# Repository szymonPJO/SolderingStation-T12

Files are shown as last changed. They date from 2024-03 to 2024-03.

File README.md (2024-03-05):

# Soldering station T12

<table>
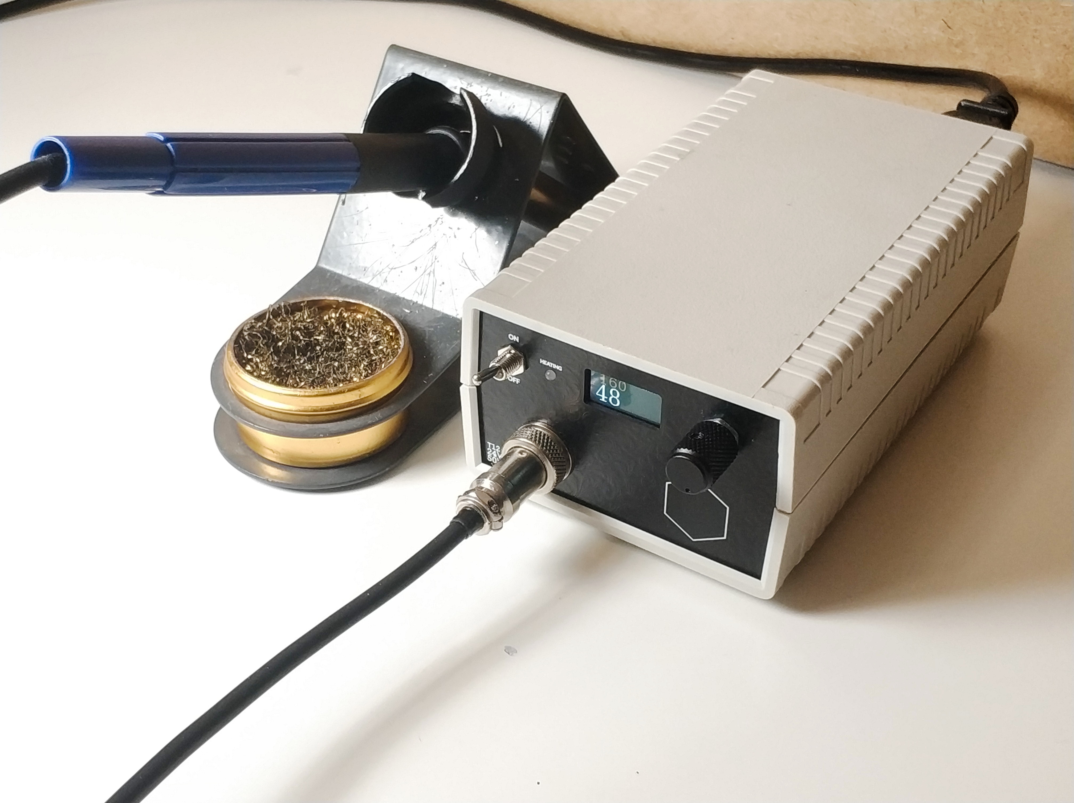
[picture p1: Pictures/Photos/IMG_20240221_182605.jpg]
station view 1
    <td></td>
</table>

## Specification:

- **Ramp-up Time**: 5 seconds to achieve 200°C
- **Measurement Accuracy**: up to ±5%
- **Power**: 75W
- **Instability (Consistency) of Set Temperature**: ±0.2°C
- **Temperature Range**: 0 – 500°C (from room temperature)
- **Number of ADC Samples**: 250
- **Measurement Time** / **Percentage of Measurement Duration (Heating Off)**: 1.4ms / 1.4% (or 0.9ms / 0.9% for temperatures >150°C)
- **PWM Frequency** / **Measurement Frequency**: 50Hz / 10Hz
- **Other**: (futures below)

<!-- # About my motivation

elektroda.
*Translated site from polish! -->

### Features:

- T12 Tips Compatibile
- IPS Display
  - Current and Set Temperature in `°C`
  - Power Output Bar Indicator
  - Settings (PID and GUI)
- Rotary Encoder
- Touch Button (stop/start heating)
- Heating LED
- Switch 230VAC
- Front Panel - PCB made
- Connector GX16 (easy tips replacement)

#### Software Features:

- Efficient Temperature Setting - PID Controller
- Memory - Eeprom
- Autosleep (todo)

## Schematics

<table>
    <tr><img src="Pictures/Mainboard-Schematic.png" alt="Mainboard-Schematic""></tr>
    <tr>
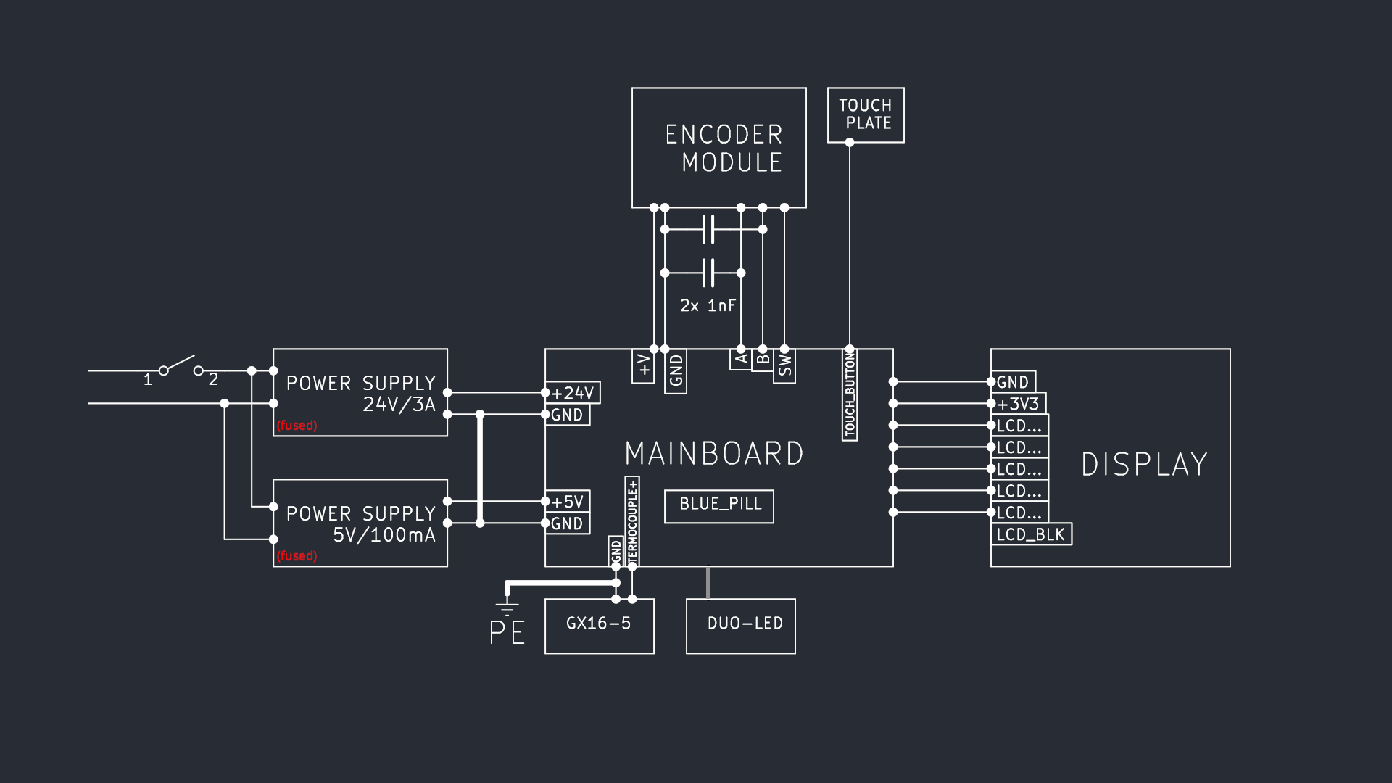
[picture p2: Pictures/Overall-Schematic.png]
Overall-Schematic
        <td></td>
    </tr>
</table>

## Software requirments

[stlink](https://github.com/stlink-org/stlink?tab=readme-ov-file), kicad (optional)

## Flashing

It's required debuger for flash STM32. STLINK-V2 clone is fine.

```bash
st-flash --reset write soldering-*.bin 0x08000000
```

If you have error then it's probably stm32 clone. It's ok. Blue-Pill boards have clons often. Check `st-info --chipid`. For clones "chipid" is 0 instead 0x0410 or similar. Try to flash with my config file.

```bash
st-flash -c doc/BP_clone.cfg --reset write soldering-*.bin 0x08000000
```

## Assembly Guide

1. First take a look at overall BOM below. Next check [PCB BOM online][preview-bom-v1] or as file in `PCB/{version}/bom/ibom.html`. (I suggest to dowload the repo this point)

   | Part                  | Description                                             | Photo                                                                    |
   | --------------------- | ------------------------------------------------------- | ------------------------------------------------------------------------ |
   | PCB components        | All important components from [PCB BOM][preview-bom-v1] |                                                                          |
   | Housing               | Gainta G762                                             |                                                                          |
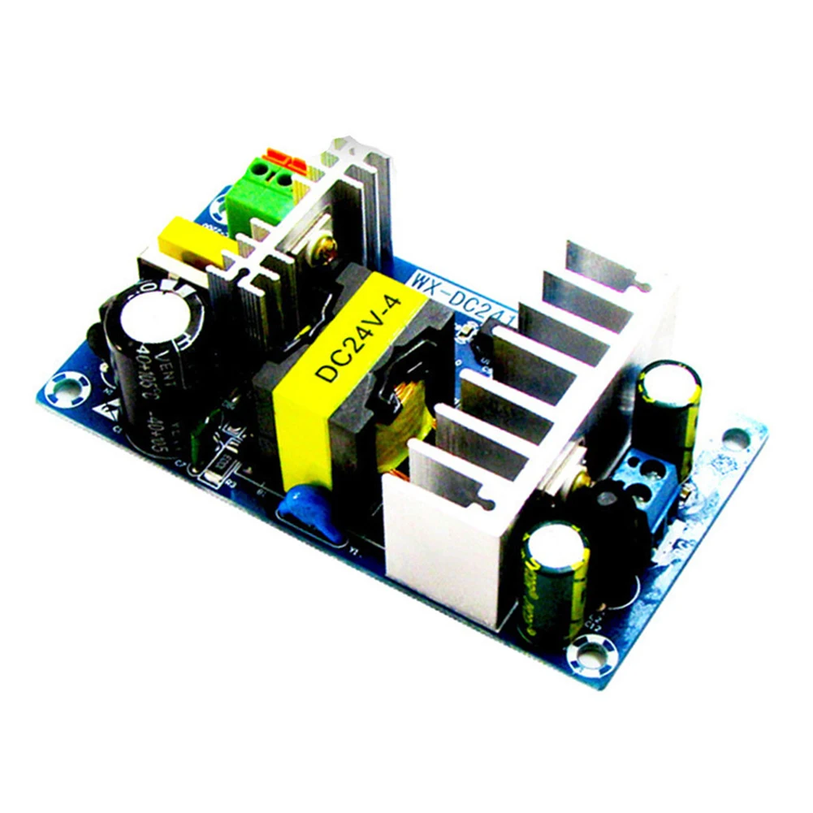
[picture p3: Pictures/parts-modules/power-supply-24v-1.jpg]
   | Power Supply 24V      | 24V/3A or more current (e.g. 24V/4A)                    |     |
   | Power Supply 5V       | 5V/100mA or more current                                |                                                                          |
   | MCU                   | Blue Pill board                                         |                                                                          |
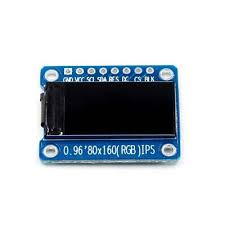
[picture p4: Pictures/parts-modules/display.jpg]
oled
   | Display               | ST7735 SPI 160x80 0.96" module                          |     |
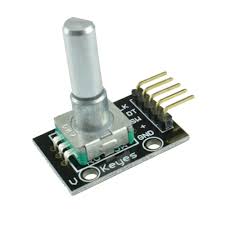
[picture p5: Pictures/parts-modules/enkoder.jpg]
encoder
   | Encoder               | Rotary Encoder module                                   |  |
   | Soldering Iron Socket | GX16-5 Socket                                           |                                                                          |
   | Front Panel           | PCB front panel (project in repo folder)                |                                                                          |
   | Knob                  | Knob for encoder                                        |                                                                          |
   | AC Switch             | SPDT                                                    |                                                                          |
   | Other components      | LED or duoLED 3mm, 2x 1nF THT                           |                                                                          |

   Make sure u have all what you need to DIY. Good to check all parts works berore u start assembly

2. If u making PCB by own, remember to:
   <!-- - U can use _Ready-to-print.pdf_ for e.g. iron-on method -->

   - Protect copper by e.g. Rosin
   - Solder wires from "F.cu" layer (may be before drilling, except two connections)
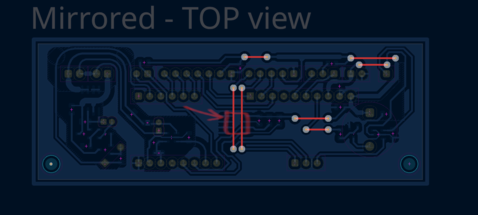
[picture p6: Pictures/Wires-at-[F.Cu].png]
Tekst zastępczy
     

   If u order PCB, remember u can also order PCB-front-board together

3. Soldering SMD (**after drilling**) - BOM [online][preview-bom-v1] or `PCB/*/bom/` can help
4. Soldering THT
5. Mount 24V power supply to device housing and **make separation** between PCB (Plan this housing from mountings things inside)

6. Make power wires from overall schematic for: _Switch, Power suplies, AC connector_ (**Isolate 230V wires and connections**)
7. Make wires and solder from overall schematic (for: _Display, Encoder, etc_) and add 2x 1nF to Encoder module if there is no capacitors
8. **Isolate** and Mount (glue) 5V power supply
9. Connect all together, burn binary and **check that's working**
10. Glue OLED while device works (it would be easier to nice match) to (if u have) PCB-front-board.
11. Let's put everything together now

### Additional assembly tips

- **Be careful** with **AC Power**

- required tools:

  - some working soldering iron (it's funny, but not ironically)
  - some glue (e.g. hotglue or b7000)
  - drilling machine, drills: ~3mm, 0,7mm, 0,9mm (look at kicad brd)
  - tweezer
  - (optional) crimping tool for Dupont Connectors

- good to use:

  - 2.54mm angle pin header + Dupont female Connectors

- Front Panel

  U have to order PCB or drill by CNC. Alternativly try to print 'cut edges' on paper and cut housing plastic plate by knife / drill. The G762 housing have bit soft plastic (maybe ABS) - front/back plates.

## Gallery

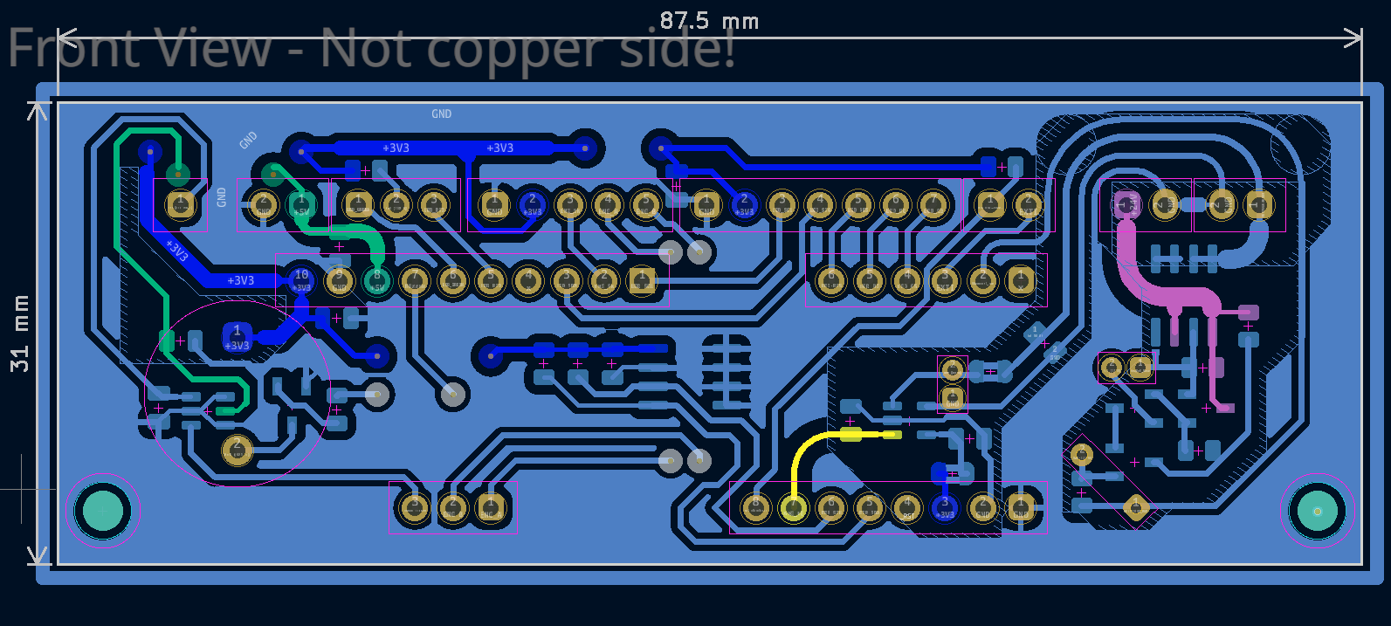
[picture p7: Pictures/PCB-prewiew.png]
PCB preview

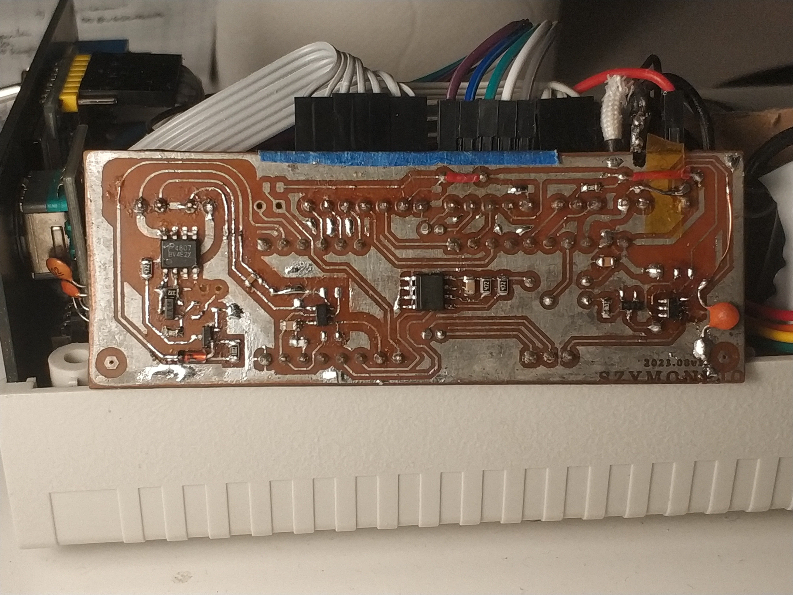
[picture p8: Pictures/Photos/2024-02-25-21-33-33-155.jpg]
PCB after soldering


Check the `Pictures/` folder! :)

---

#### Imagined Concept:

What I decide to leave at concept phase:

- 907 tips compatibility
- tips recognizing
- measurement of thermocouple cold junction thermistor
- optional li-ion power

### Contributing

Feel free to open Pull Request or some Issue

---



[preview-bom-v1]: https://html-preview.github.io/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

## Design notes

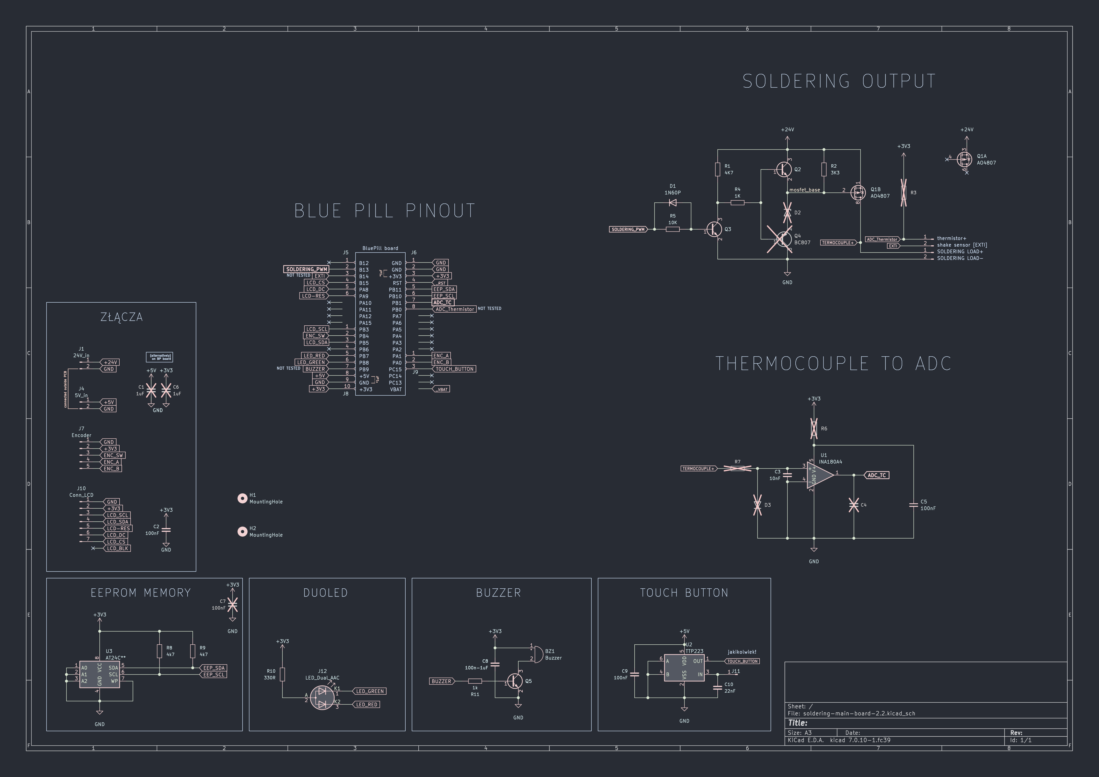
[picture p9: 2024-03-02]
Pictures/Mainboard-Schematic.png

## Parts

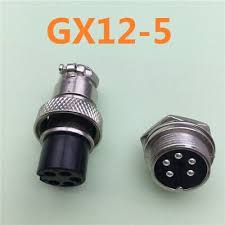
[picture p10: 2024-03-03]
Pictures/parts-modules/GX12-5.jpg

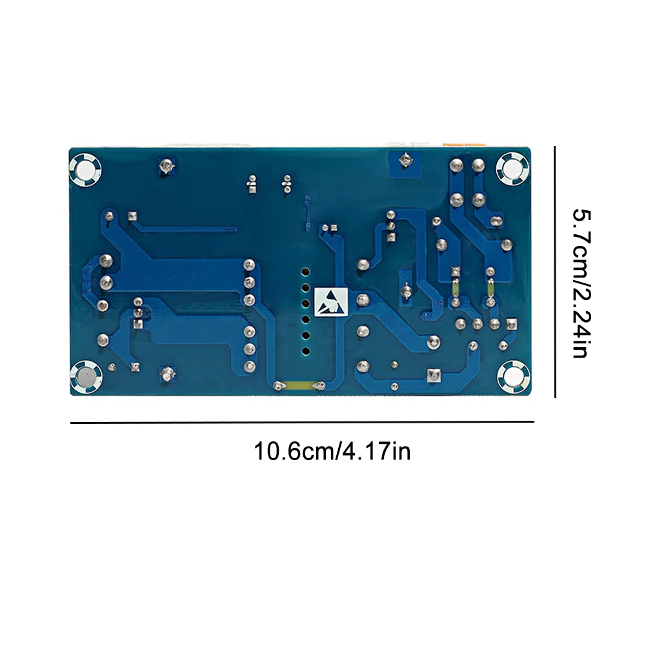
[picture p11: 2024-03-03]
Pictures/parts-modules/power-supply-24v-2.jpg

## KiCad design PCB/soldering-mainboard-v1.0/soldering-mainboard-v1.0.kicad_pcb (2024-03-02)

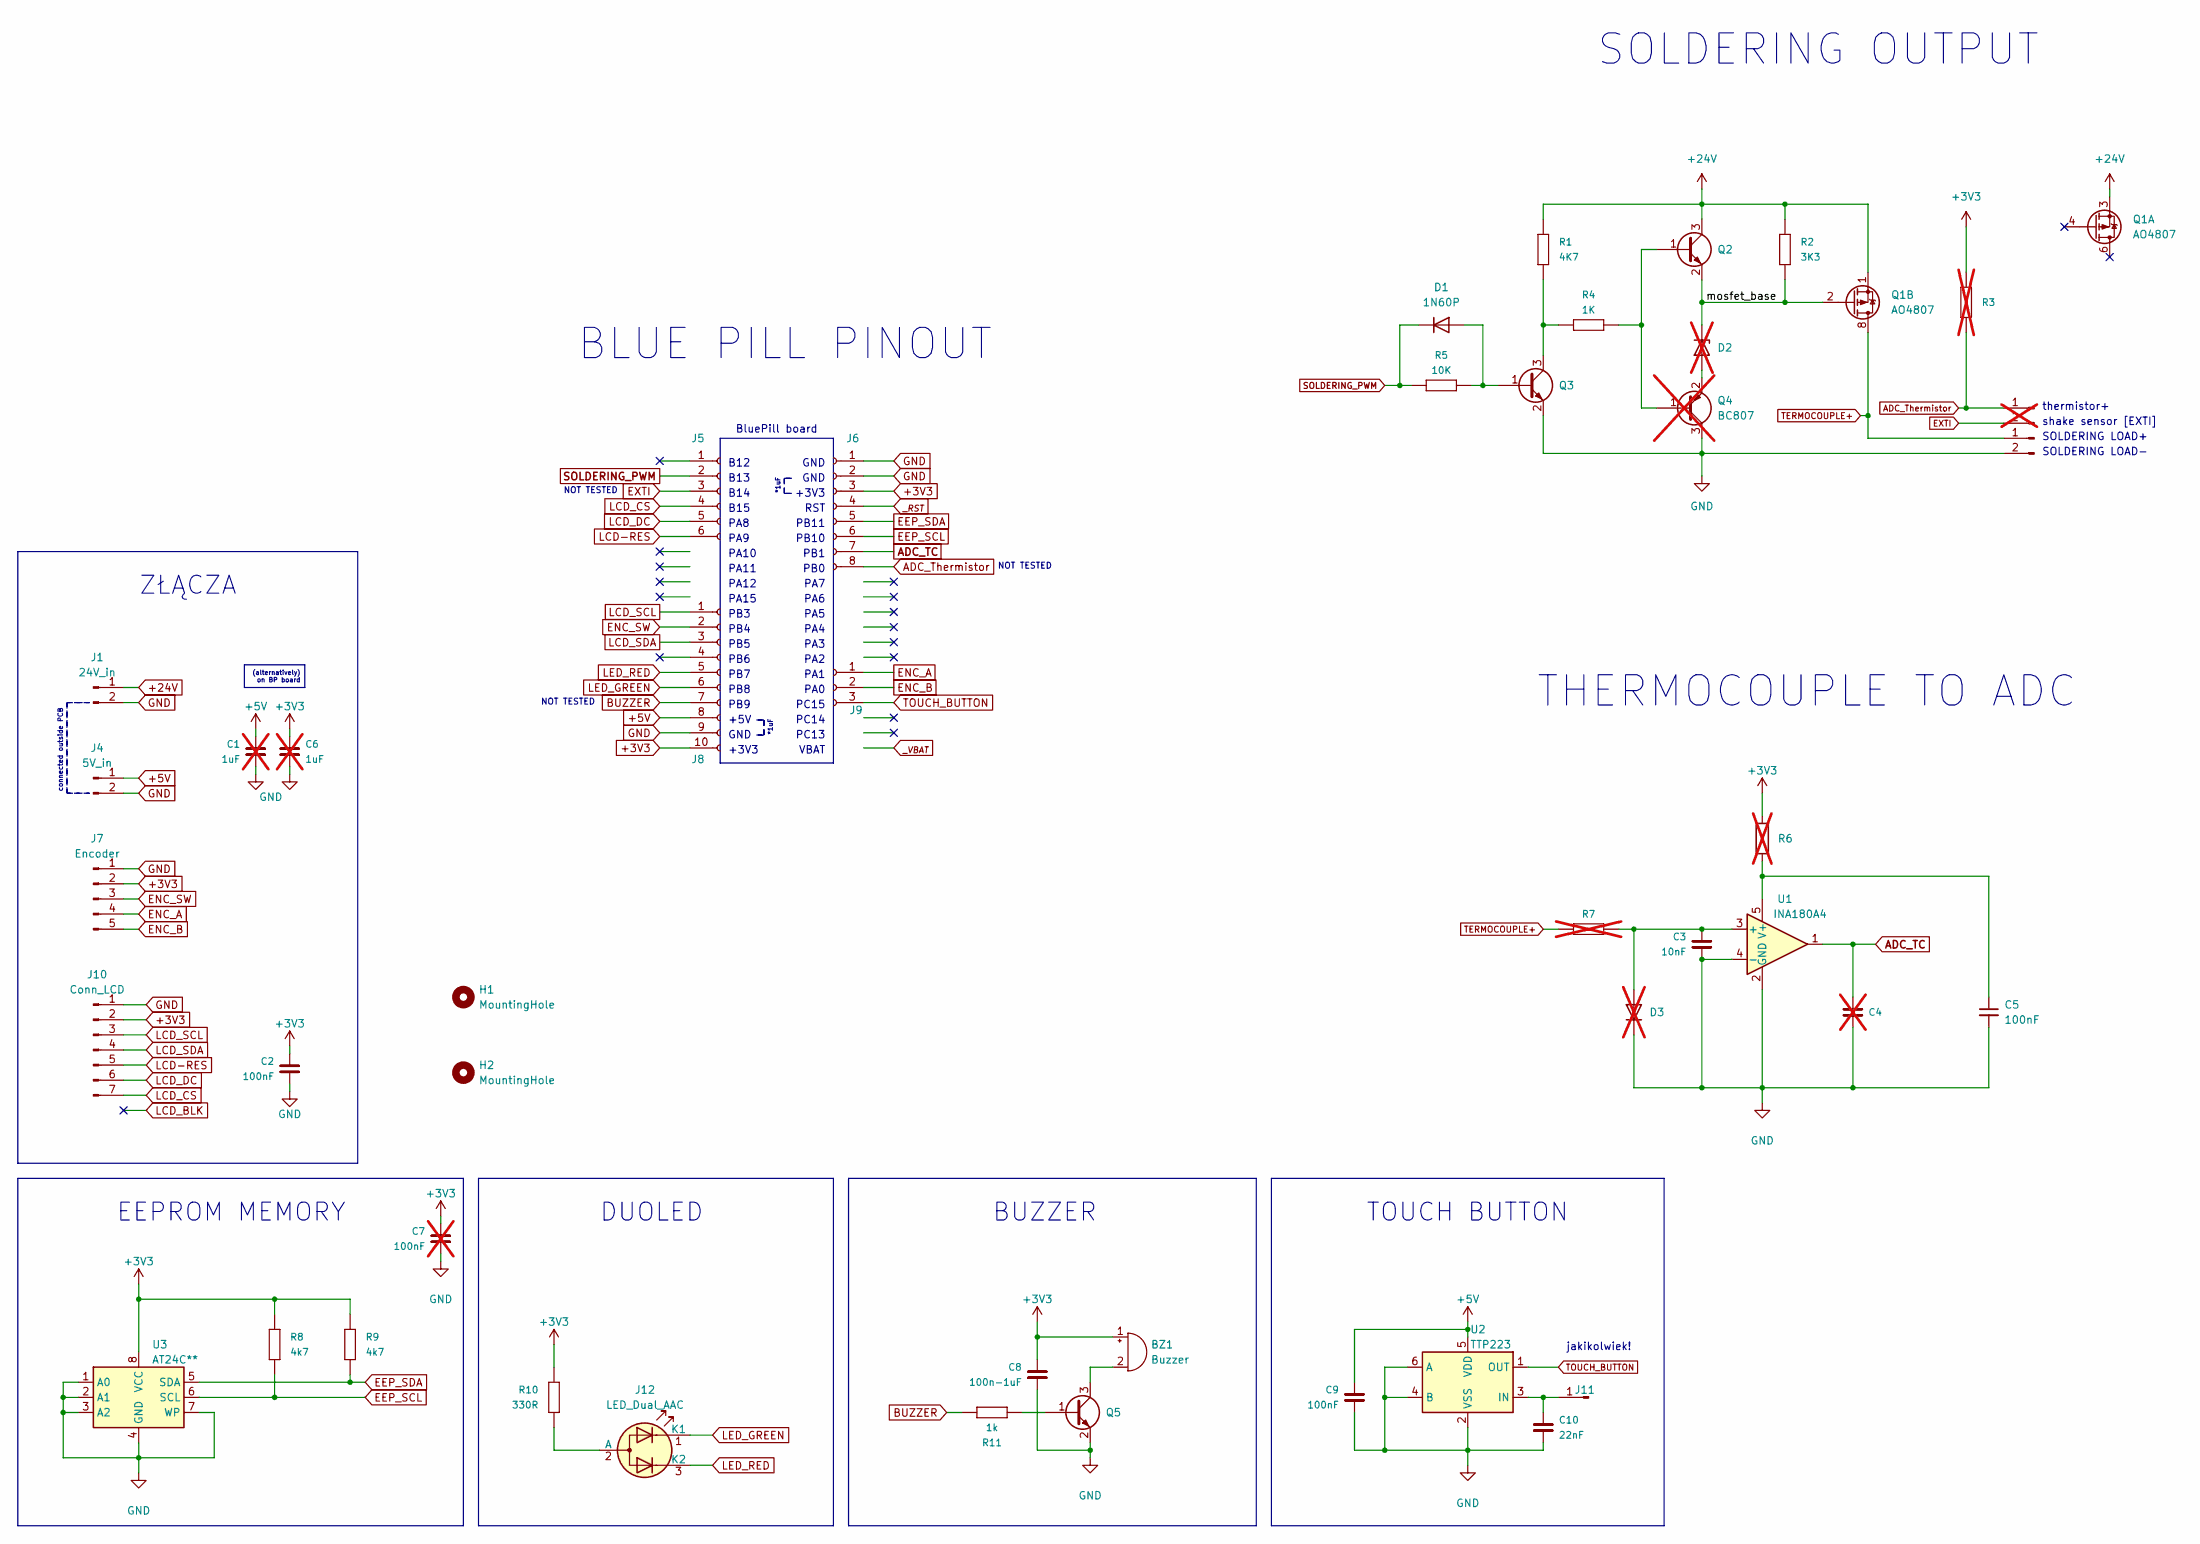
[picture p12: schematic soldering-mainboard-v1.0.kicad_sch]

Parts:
BZ1: Buzzer; Buzzer_12x9.5RM7.6
C1, C6: 1uF; C_0805_2012Metric; not fitted
C2, C5, C9: 100nF; C_0805_2012Metric
C3: 10nF; C_0805_2012Metric
C4: C_0805_2012Metric; not fitted
C7: 100nF; C_0805_2012Metric; not fitted
C8: 100n-1uF; C_0805_2012Metric
C10: 22nF; C_0805_2012Metric
D1: 1N60P; D_DO-34_SOD68_P5.08mm_Vertical_AnodeUp
D2, D3: D_Axial_P1.90mm_Vertical; not fitted
H1, H2: MountingHole; MountingHole_2.7mm_M2.5_ISO14580
J1: 24V_in; PinHeader_1x02_P2.54mm_Vertical
J2: PinHeader_1x02_P2.54mm_Vertical; not fitted
J3: Soldering Iron; PinHeader_1x02_P2.54mm_Vertical
J4: 5V_in; PinHeader_1x02_P2.54mm_Vertical
J5: Conn_01x06_Socket; PinSocket_1x06_P2.54mm_Vertical
J6: Conn_01x08_Socket; PinSocket_1x08_P2.54mm_Vertical
J7: Encoder; PinHeader_1x05_P2.54mm_Vertical
J8: Conn_01x10_Socket; PinSocket_1x10_P2.54mm_Vertical
J9: Conn_01x03_Socket; PinSocket_1x03_P2.54mm_Vertical
J10: Conn_LCD; PinHeader_1x07_P2.54mm_Vertical
J11: Conn_01x01_Male; PinHeader_1x01_P2.54mm_Vertical
J12: LED_Dual_AAC; PinHeader_1x03_P2.54mm_Vertical
Q1: AO4807; SOIC-8_3.9x4.9mm_P1.27mm
Q2, Q3, Q5: MMBT3904; TSOT-23
Q4: BC807; TSOT-23; not fitted
R1: 4K7; R_0805_2012Metric
R2: 3K3; R_0805_2012Metric
R3: R_0805_2012Metric; not fitted
R4: 1K; R_0805_2012Metric
R5: 10K; R_0805_2012Metric
R6, R7: SolderJumper-2_P1.9mm_Closed; not fitted
R8, R9: 4k7; R_0805_2012Metric
R10: 330R; R_0805_2012Metric
R11: 1k; R_0805_2012Metric
U1: INA180A4; SOT-23-5
U2: TTP223; SOT-23-6
U3: AT24C**; SOIC-8_3.9x4.9mm_P1.27mm

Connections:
+3V3: BZ1.1 (-), C2.1, C7.1, C8.1, J6.3, J7.2, J8.10, J10.2, R3.2, R6.2, R8.2, R9.2, R10.2, U3.8 (VCC)
+5V: C1.1, C9.1, J4.1, J8.8, U2.5 (VDD)
+24V: J1.1, Q1.1 (S2), Q1.3 (S1), Q2.3 (C), R1.2, R2.2
/mosfet_base: D2.1 (K), Q1.2 (G2), Q2.2 (E), R2.1
ADC_TC: C4.1, J6.7, U1.1
ADC_Thermistor: J2.1, J6.8, R3.1
BUZZER: J8.7, R11.2
EEP_SCL: J6.6, R8.1, U3.6 (SCL)
EEP_SDA: J6.5, R9.1, U3.5 (SDA)
ENC_A: J7.4, J9.1
ENC_B: J7.5, J9.2
ENC_SW: J7.3, J8.2
EXTI: J2.2, J5.3
GND: C1.2, C2.2, C3.2, C4.2, C5.2, C7.2, C8.2, C9.2, C10.2, D3.1 (K), J1.2, J3.2, J4.2, J6.1, J6.2, J7.1, J8.9, J10.1, Q3.2 (E), Q4.3 (C), Q5.2 (E), U1.2 (GND), U1.4 (-), U2.2 (VSS), U2.4 (B), U2.6 (A), U3.1 (A0), U3.2 (A1), U3.3 (A2), U3.4 (GND), U3.7 (WP)
LCD-RES: J5.6, J10.5
LCD_CS: J5.4, J10.7
LCD_DC: J5.5, J10.6
LCD_SCL: J8.1, J10.3
LCD_SDA: J8.3, J10.4
LED_GREEN: J8.6, J12.1 (K1)
LED_RED: J8.5, J12.3 (K2)
unnamed: BZ1.2 (+), Q5.3 (C)
unnamed: D1.2 (A), Q3.1 (B), R5.2
unnamed: D2.2 (A), Q4.2 (E)
unnamed: C3.1, D3.2 (A), R7.2, U1.3 (+)
unnamed: C10.1, J11.1, U2.3 (IN)
unnamed: J12.2 (A), R10.1
unnamed: Q2.1 (B), Q4.1 (B), R4.2
unnamed: Q3.3 (C), R1.1, R4.1
unnamed: Q5.1 (B), R11.1
unnamed: C5.1, R6.1, U1.5 (V+)
SOLDERING_PWM: D1.1 (K), J5.2, R5.1
TERMOCOUPLE+: J3.1, Q1.7 (D2), Q1.8 (D2), R7.1
TOUCH_BUTTON: J9.3, U2.1 (OUT)
_{_RST}: J6.4

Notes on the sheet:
(alternatively) on BP board
PA9
DUOLED
PA2
TOUCH BUTTON
PA7
+5V
ZŁĄCZA
SOLDERING LOAD-
PA15
PC14
jakikolwiek!
PA5
PB5
PA0
NOT TESTED
PB10
VBAT
PB3
B15
PB9
BLUE PILL PINOUT
GND
THERMOCOUPLE TO ADC
*1uF
B13
B14
PA3
B12
PA12
PA10
+3V3
PB7
PA8
PA1
shake sensor [EXTI]
PB8
PB4
PB6
PA11

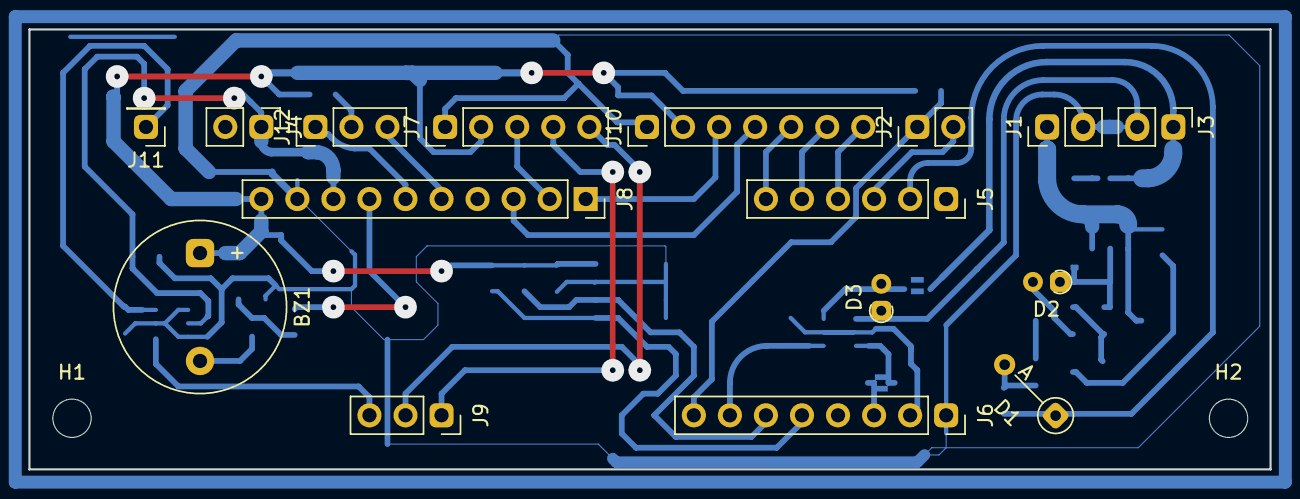
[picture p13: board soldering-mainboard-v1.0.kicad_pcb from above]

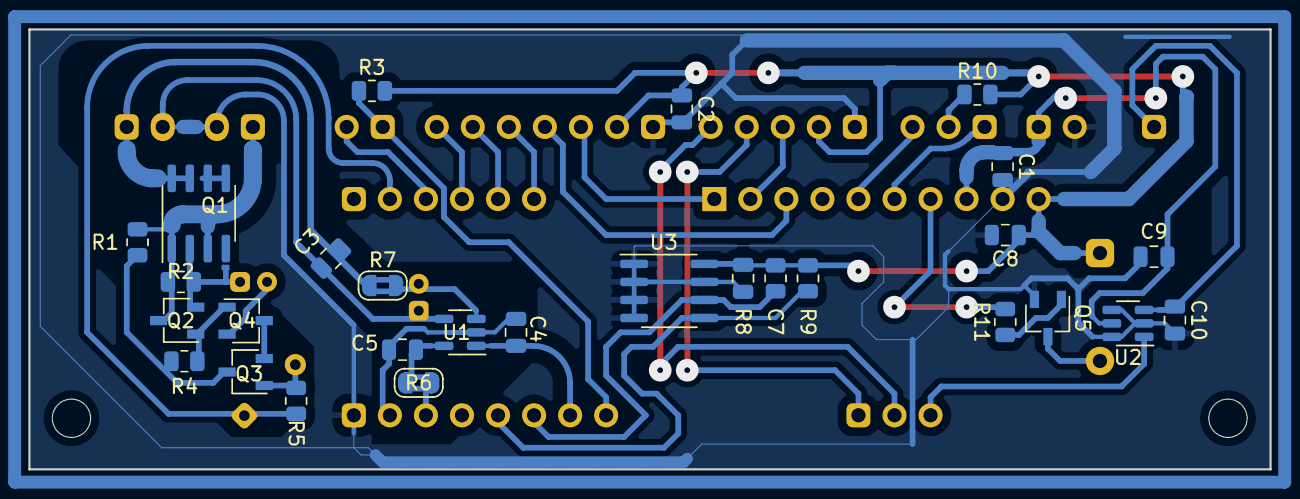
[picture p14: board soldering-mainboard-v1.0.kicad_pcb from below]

Board: 4 copper layers, 87.5 x 31.0 mm, 46 parts (28 on the bottom side), 34 nets.

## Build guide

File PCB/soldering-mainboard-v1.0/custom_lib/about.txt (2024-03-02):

Partially copied from: https://github.com/Szymono/KiCad_library

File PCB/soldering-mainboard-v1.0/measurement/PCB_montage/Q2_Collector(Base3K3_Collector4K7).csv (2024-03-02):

Time [s] | CH1 [V] | CH2 [V]
2.000000e-09 | 0.600000000000 | 3.400000000000
2.000000e-09 | 0.400000000000 | 3.200000000000
2.000000e-09 | 0.200000000000 | 3.400000000000
2.000000e-09 | 0.400000000000 | 3.200000000000
2.000000e-09 | 0.600000000000 | 3.200000000000
2.000000e-09 | 0.400000000000 | 3.200000000000
2.000000e-09 | 0.400000000000 | 3.400000000000
2.000000e-09 | 0.400000000000 | 3.200000000000
2.000000e-09 | 0.400000000000 | 3.200000000000
2.000000e-09 | 0.400000000000 | 3.200000000000
2.000000e-09 | 0.400000000000 | 3.200000000000
2.000000e-09 | 0.400000000000 | 3.400000000000
2.000000e-09 | 0.400000000000 | 3.400000000000
2.000000e-09 | 0.400000000000 | 3.200000000000
2.000000e-09 | 0.400000000000 | 3.400000000000
2.000000e-09 | 0.400000000000 | 3.200000000000
2.000000e-09 | 0.600000000000 | 3.200000000000
2.000000e-09 | 0.400000000000 | 3.200000000000
2.000000e-09 | 0.400000000000 | 3.400000000000
2.000000e-09 | 0.600000000000 | 3.200000000000
2.000000e-09 | 0.400000000000 | 3.200000000000
2.000000e-09 | 0.400000000000 | 3.400000000000
2.000000e-09 | 0.400000000000 | 3.200000000000
2.000000e-09 | 0.400000000000 | 3.200000000000
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

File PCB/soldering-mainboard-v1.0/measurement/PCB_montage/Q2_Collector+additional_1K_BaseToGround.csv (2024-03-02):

Time [s] | CH1 [V] | CH2 [V]
2.000000e-09 | 0.400000000000 | 3.200000000000
2.000000e-09 | 0.200000000000 | 3.000000000000
2.000000e-09 | 0.400000000000 | 3.400000000000
2.000000e-09 | 0.600000000000 | 3.200000000000
2.000000e-09 | 0.400000000000 | 3.400000000000
2.000000e-09 | 0.400000000000 | 3.400000000000
2.000000e-09 | 0.600000000000 | 3.600000000000
2.000000e-09 | 0.400000000000 | 3.200000000000
2.000000e-09 | 0.400000000000 | 3.200000000000
2.000000e-09 | 0.600000000000 | 3.200000000000
2.000000e-09 | 0.400000000000 | 3.400000000000
2.000000e-09 | 0.600000000000 | 3.200000000000
2.000000e-09 | 0.400000000000 | 3.400000000000
2.000000e-09 | 0.600000000000 | 3.200000000000
2.000000e-09 | 0.400000000000 | 3.400000000000
2.000000e-09 | 0.400000000000 | 3.200000000000
2.000000e-09 | 0.400000000000 | 3.400000000000
2.000000e-09 | 0.600000000000 | 3.200000000000
2.000000e-09 | 0.400000000000 | 3.400000000000
2.000000e-09 | 0.400000000000 | 3.200000000000
2.000000e-09 | 0.600000000000 | 3.200000000000
2.000000e-09 | 0.600000000000 | 3.200000000000
2.000000e-09 | 0.600000000000 | 3.400000000000
2.000000e-09 | 0.400000000000 | 3.200000000000
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

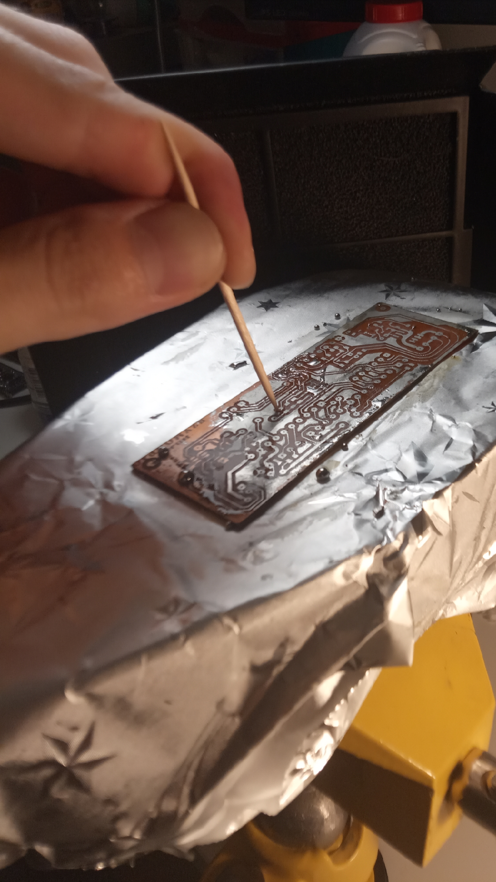
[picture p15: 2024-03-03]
Pictures/Photos/making-copper-protection.png

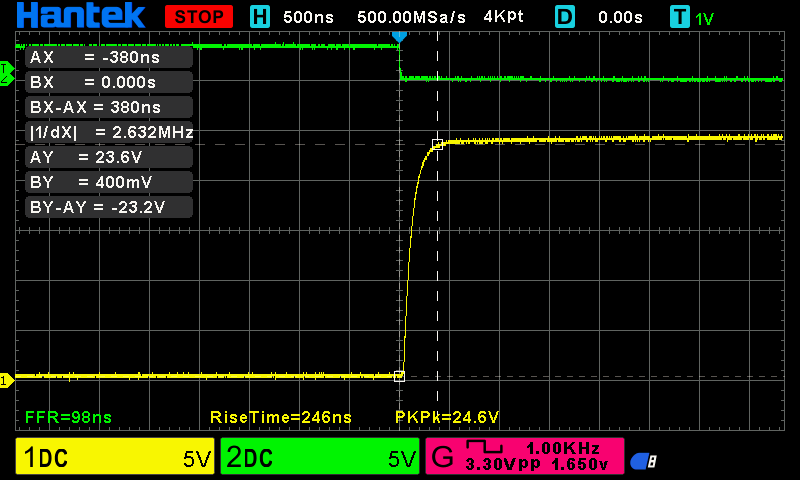
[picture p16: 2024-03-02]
PCB/soldering-mainboard-v1.0/measurement/PCB_montage/Q2_Collector+additional_1K_BaseToGround.bmp

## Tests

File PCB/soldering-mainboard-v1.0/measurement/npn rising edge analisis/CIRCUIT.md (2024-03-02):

The test circuit:

#### NPN

- 3V3, 1k - base
- 24V, 4k8 - collector (power)
- GND - Emitter 

Square wave input (CH2). Output (CH1)

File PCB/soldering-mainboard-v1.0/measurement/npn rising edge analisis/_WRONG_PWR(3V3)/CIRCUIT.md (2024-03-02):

The test circuit:

#### NPN

- 3V3, 1k - base
- 3V3, 4k8 - collector (power)
- GND - Emitter 

Square wave input (CH2). Output (CH1)

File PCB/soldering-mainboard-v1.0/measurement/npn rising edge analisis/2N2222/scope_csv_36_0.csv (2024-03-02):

Time [s] | CH1 [V] | CH2 [V]
2.000000e-09 | 0.200000000000 | 3.200000000000
2.000000e-09 | 0.200000000000 | 3.280000000000
2.000000e-09 | 0.200000000000 | 3.280000000000
2.000000e-09 | 0.200000000000 | 3.200000000000
2.000000e-09 | 0.200000000000 | 3.200000000000
2.000000e-09 | 0.200000000000 | 3.200000000000
2.000000e-09 | 0.200000000000 | 3.200000000000
2.000000e-09 | 0.200000000000 | 3.200000000000
2.000000e-09 | 0.400000000000 | 3.200000000000
2.000000e-09 | 0.200000000000 | 3.280000000000
2.000000e-09 | 0.200000000000 | 3.280000000000
2.000000e-09 | 0.200000000000 | 3.200000000000
2.000000e-09 | 0.400000000000 | 3.200000000000
2.000000e-09 | 0.200000000000 | 3.280000000000
2.000000e-09 | 0.200000000000 | 3.280000000000
2.000000e-09 | 0.200000000000 | 3.280000000000
2.000000e-09 | 0.200000000000 | 3.280000000000
2.000000e-09 | 0.200000000000 | 3.280000000000
2.000000e-09 | 0.400000000000 | 3.280000000000
2.000000e-09 | 0.200000000000 | 3.200000000000
2.000000e-09 | 0.200000000000 | 3.280000000000
2.000000e-09 | 0.200000000000 | 3.280000000000
2.000000e-09 | 0.200000000000 | 3.280000000000
2.000000e-09 | 0.200000000000 | 3.200000000000
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

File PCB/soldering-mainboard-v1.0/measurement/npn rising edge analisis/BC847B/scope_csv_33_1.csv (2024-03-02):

Time [s] | CH1 [V] | CH2 [V]
2.000000e-09 | 0.200000000000 | 3.120000000000
2.000000e-09 | 0.600000000000 | 3.200000000000
2.000000e-09 | 0.400000000000 | 3.120000000000
2.000000e-09 | 0.200000000000 | 3.200000000000
2.000000e-09 | 0.200000000000 | 3.200000000000
2.000000e-09 | 0.200000000000 | 3.200000000000
2.000000e-09 | 0.400000000000 | 3.120000000000
2.000000e-09 | 0.200000000000 | 3.200000000000
2.000000e-09 | 0.400000000000 | 3.200000000000
2.000000e-09 | 0.200000000000 | 3.200000000000
2.000000e-09 | 0.200000000000 | 3.200000000000
2.000000e-09 | 0.200000000000 | 3.200000000000
2.000000e-09 | 0.200000000000 | 3.200000000000
2.000000e-09 | 0.400000000000 | 3.200000000000
2.000000e-09 | 0.200000000000 | 3.120000000000
2.000000e-09 | 0.000000000000 | 3.200000000000
2.000000e-09 | 0.200000000000 | 3.120000000000
2.000000e-09 | 0.400000000000 | 3.200000000000
2.000000e-09 | 0.200000000000 | 3.200000000000
2.000000e-09 | 0.200000000000 | 3.200000000000
2.000000e-09 | 0.200000000000 | 3.120000000000
2.000000e-09 | 0.400000000000 | 3.200000000000
2.000000e-09 | 0.400000000000 | 3.200000000000
2.000000e-09 | 0.400000000000 | 3.200000000000
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

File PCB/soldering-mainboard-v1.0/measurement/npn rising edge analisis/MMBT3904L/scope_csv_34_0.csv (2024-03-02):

Time [s] | CH1 [V] | CH2 [V]
2.000000e-09 | 0.400000000000 | 3.200000000000
2.000000e-09 | 0.200000000000 | 3.200000000000
2.000000e-09 | 0.200000000000 | 3.280000000000
2.000000e-09 | 0.400000000000 | 3.280000000000
2.000000e-09 | 0.400000000000 | 3.280000000000
2.000000e-09 | 0.200000000000 | 3.200000000000
2.000000e-09 | 0.400000000000 | 3.200000000000
2.000000e-09 | 0.400000000000 | 3.200000000000
2.000000e-09 | 0.400000000000 | 3.200000000000
2.000000e-09 | 0.400000000000 | 3.200000000000
2.000000e-09 | 0.400000000000 | 3.200000000000
2.000000e-09 | 0.400000000000 | 3.200000000000
2.000000e-09 | 0.200000000000 | 3.280000000000
2.000000e-09 | 0.400000000000 | 3.280000000000
2.000000e-09 | 0.400000000000 | 3.200000000000
2.000000e-09 | 0.400000000000 | 3.200000000000
2.000000e-09 | 0.400000000000 | 3.200000000000
2.000000e-09 | 0.200000000000 | 3.200000000000
2.000000e-09 | 0.200000000000 | 3.200000000000
2.000000e-09 | 0.200000000000 | 3.200000000000
2.000000e-09 | 0.400000000000 | 3.200000000000
2.000000e-09 | 0.400000000000 | 3.200000000000
2.000000e-09 | 0.400000000000 | 3.200000000000
2.000000e-09 | 0.200000000000 | 3.200000000000
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

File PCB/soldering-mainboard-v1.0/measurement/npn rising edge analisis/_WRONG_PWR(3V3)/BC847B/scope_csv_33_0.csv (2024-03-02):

Time [s] | CH1 [V] | CH2 [V]
2.000000e-09 | 0.040000000000 | 3.200000000000
2.000000e-09 | 0.040000000000 | 3.200000000000
2.000000e-09 | 0.040000000000 | 3.200000000000
2.000000e-09 | 0.080000000000 | 3.200000000000
2.000000e-09 | 0.040000000000 | 3.280000000000
2.000000e-09 | 0.040000000000 | 3.200000000000
2.000000e-09 | 0.040000000000 | 3.200000000000
2.000000e-09 | 0.040000000000 | 3.200000000000
2.000000e-09 | 0.040000000000 | 3.200000000000
2.000000e-09 | 0.040000000000 | 3.200000000000
2.000000e-09 | 0.040000000000 | 3.200000000000
2.000000e-09 | 0.040000000000 | 3.200000000000
2.000000e-09 | 0.040000000000 | 3.200000000000
2.000000e-09 | 0.080000000000 | 3.280000000000
2.000000e-09 | 0.080000000000 | 3.200000000000
2.000000e-09 | 0.040000000000 | 3.280000000000
2.000000e-09 | 0.040000000000 | 3.200000000000
2.000000e-09 | 0.080000000000 | 3.280000000000
2.000000e-09 | 0.040000000000 | 3.200000000000
2.000000e-09 | 0.000000000000 | 3.280000000000
2.000000e-09 | 0.040000000000 | 3.200000000000
2.000000e-09 | 0.080000000000 | 3.280000000000
2.000000e-09 | 0.040000000000 | 3.200000000000
2.000000e-09 | 0.040000000000 | 3.200000000000
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

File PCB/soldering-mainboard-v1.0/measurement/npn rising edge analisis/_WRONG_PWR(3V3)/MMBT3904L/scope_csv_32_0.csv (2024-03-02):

Time [s] | CH1 [V] | CH2 [V]
2.000000e-09 | 0.040000000000 | 3.120000000000
2.000000e-09 | 0.040000000000 | 3.120000000000
2.000000e-09 | 0.040000000000 | 3.120000000000
2.000000e-09 | 0.040000000000 | 3.120000000000
2.000000e-09 | 0.040000000000 | 3.120000000000
2.000000e-09 | 0.040000000000 | 3.120000000000
2.000000e-09 | 0.040000000000 | 3.120000000000
2.000000e-09 | 0.040000000000 | 3.120000000000
2.000000e-09 | 0.040000000000 | 3.120000000000
2.000000e-09 | 0.080000000000 | 3.120000000000
2.000000e-09 | 0.040000000000 | 3.120000000000
2.000000e-09 | 0.040000000000 | 3.120000000000
2.000000e-09 | 0.080000000000 | 3.120000000000
2.000000e-09 | 0.120000000000 | 3.120000000000
2.000000e-09 | 0.080000000000 | 3.120000000000
2.000000e-09 | 0.040000000000 | 3.120000000000
2.000000e-09 | 0.120000000000 | 3.120000000000
2.000000e-09 | 0.040000000000 | 3.040000000000
2.000000e-09 | 0.040000000000 | 3.120000000000
2.000000e-09 | 0.080000000000 | 3.120000000000
2.000000e-09 | 0.080000000000 | 3.120000000000
2.000000e-09 | 0.040000000000 | 3.120000000000
2.000000e-09 | 0.040000000000 | 3.120000000000
2.000000e-09 | 0.080000000000 | 3.120000000000
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

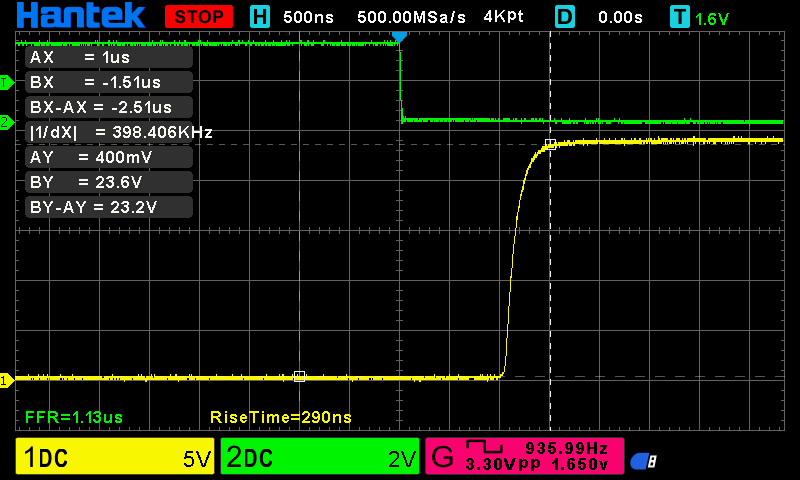
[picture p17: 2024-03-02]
PCB/soldering-mainboard-v1.0/measurement/npn rising edge analisis/BC547 (THT)/dso_01_01_00_10_42.bmp

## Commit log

2022-01-24 errata i2c img
2024-03-02 update ;)
    In other words, this is first commit after long break. More like initial commit
    [BP_clone.cfg, soldering-frontpanel-v2.kicad_pcb, soldering-mainboard-v1.0.kicad_pcb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]
2024-03-02 doc: link to html-preview from PCB v1
2024-03-02 mesurements and simulations
    [Q2_Collector(Base3K3_Collector4K7).csv, Q2_Collector+additional_1K_BaseToGround.csv, scope_csv_32_0.csv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]
2024-03-05 doc: pics device inside

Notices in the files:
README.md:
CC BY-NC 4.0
